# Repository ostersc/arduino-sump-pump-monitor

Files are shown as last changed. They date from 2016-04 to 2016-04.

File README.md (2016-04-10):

# arduino-sump-pump-monitor
Arduino project for ESP8266 to monitor backup sump pump and water level, sending alerts upon issues.

The project monitors my sump pump for when its backup pump engages, or when the main pump is running on battery power (due to power outage).  The project continually monitors the pumps, reporting data to thingspeak.com indicating the pump status.  The board is equiped with a LiPo battery backup, so it is still able to report in the event of a power outage.
Graph

## PUMP
I have the Basement Watchdog BW4000 Sump Pump, which has a backup pump, battery, and remote terminal to indicate alarms.
http://www.basementwatchdog.com/Basement_Watchdog_Combination_Systems.php
http://www.basementwatchdog.com/Accessories/Remote_Terminal.php
Any similar system could be used, or a homebrew sensor could be created, as all this "remote terminal" does is provide an open/closed circuit transition when triggering an alarm.

## HARDWARE
I'm using the Sparkfun ESP8266 Thing (https://www.sparkfun.com/products/13231).
The Adafruit Feather HUZZAH actually looks easier to program; it should work as well (https://www.adafruit.com/products/2821)
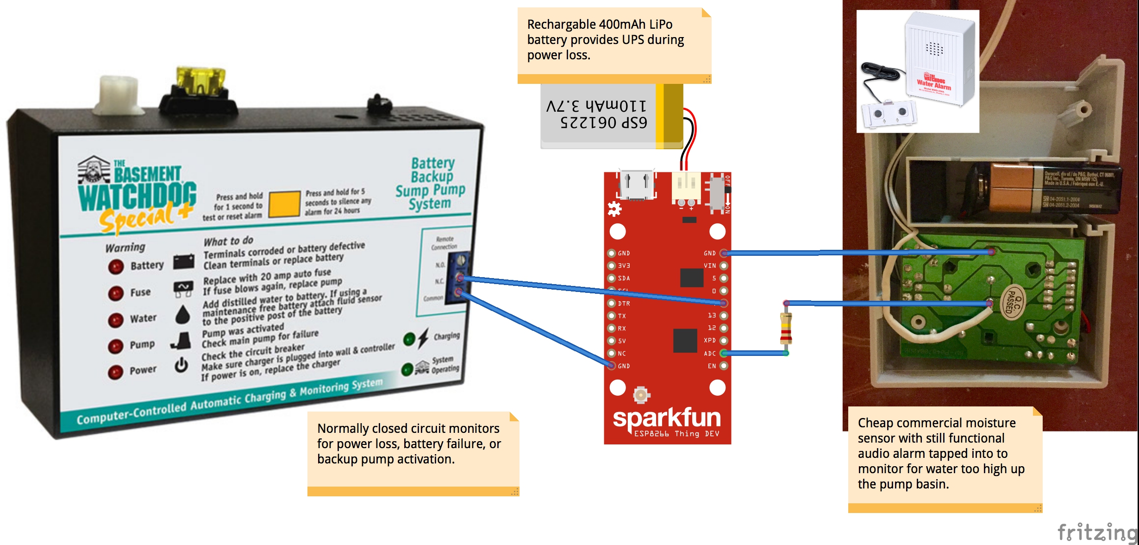
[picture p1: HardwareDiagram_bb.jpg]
Wiring


## CURRENT STATUS
*  Sump alarm monitoring (backup pump used, power loss, fuse, or battery issue)
*  Sump basin Water level alarm (moisture sensor mounted above backup float)
*  Reporting to thingspeak (signal strength, alarm state, alarm duration, alarm count)
* Email when alarm or water level alarm state entered (via https://temboo.com/arduino/others/send-an-email)

## TODO
* Battery level monitoring (and maybe deep sleep) (via https://learn.adafruit.com/using-ifttt-with-adafruit-io/wiring#battery-tracking)
* Collect settings and alert email via the wifi capture screen (via https://github.com/tzapu/WiFiManager#custom-parameters)
* 3D print an enclosure

## LIBRARIES
* https://github.com/tzapu/WiFiManager
* https://github.com/mathworks/thingspeak-arduino

## SETUP
- Create a file called Secrets.h, copying the commented out block from the ino sketch
- Create a thingspeak channel [here](https://thingspeak.com/)
  - The fields should be ```id alarm alarmduration alarmcount waterlevel wateralarmcount wateralarmduration rssi```
  - Edit the myChannelNumber and myWriteAPIKey in Secrets.h
  - Channel Setup
- Follow instructions on setting up Temboo account and gmail [here](https://temboo.com/arduino/others/send-an-email)
  - copy all the TEMBOO settings from the header section (normally Temboo.h) and put in Secrets.h
- You can setup additional alarms as needed (such as no data alarms, low wifi strength, etc) by using thingspeaks ability to trigger IFTTT events [as described here](http://www.makeuseof.com/tag/ifttt-connect-anything-maker-channel/).

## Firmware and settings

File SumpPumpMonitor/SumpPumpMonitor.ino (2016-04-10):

#include <ESP8266WiFi.h>
#include "WiFiManager.h"  //https://github.com/tzapu/WiFiManager
#include "Temboo.h"  //https://temboo.com/library/ https://github.com/arduino-libraries/Temboo
#include "ThingSpeak.h" //https://github.com/mathworks/thingspeak-arduino
#include "Secrets.h"
/**
   COPY THESE INTO A FILE CALLED Secrets.h AND REPLACE THE VALUES FOR YOUR ACCOUNT
  #define TEMBOO_ACCOUNT "your account"  // Your Temboo account name
  #define TEMBOO_APP_KEY_NAME "myFirstApp"  // Your Temboo app key name
  #define TEMBOO_APP_KEY "your key"  // Your Temboo app key

  #define EMAIL_USER "example@gmail.com"
  #define EMAIL_PASSWORD "asdfasdfasdfasdfasdf"
  #define EMAIL_TO "example@gmail.com"
  #define EMAIL_CC "example@gmail.com"
  #define EMAIL_FROM "example@gmail.com"

  unsigned long myChannelNumber = 123456;
  const char * myWriteAPIKey = "yourapikey";
*/

#define ALARM_EMAIL_SUBJECT "Sump Pump Alarm Triggered!"
#define WATER_EMAIL_SUBJECT "Water in Sump Pump!"

const char* SSID = "SumpPumpMonitor";

//Thing's onboard LED
const int LED_PIN = 5;
// other pings available on Thing
const int ANALOG_PIN = A0;
//const int DIGITAL_PIN_1 = 0;
//const int DIGITAL_PIN_2 = 4;
//const int DIGITAL_PIN_3 = 12;
//const int DIGITAL_PIN_4 = 13;
const int ALARM_PIN = 4;

const int NUM_READINGS = 20;

int moistureReadings[NUM_READINGS];   // the readings from the analog input
int moistureReadIndex = 0;            // the index of the current reading
int moistureTotal = 0;                // the running total
int moistureAverage = 0;              // the average
int moistureState = LOW;
int moistureAlarmCount = 0;
const int moistureThreshold = 250;
unsigned long lastMoistureAlarm = 0;
#define DEBUG_MOISTURE false

//thingspeak only lets report every 15 seconds or so
const unsigned long postRate = 15000;
unsigned long lastPost = 0;
unsigned long lastAlarm = 0;
int alarmState = LOW;
int alarmCount = 0;
String macAddress;

// Use WiFiClient class to create TCP connections
WiFiClient client;

//comment out to disable debug output
//#define DEBUG
//WARNING: printing to the serial port while sending data over wifi, corrupts the data (at least with sparkfun's board posting to phant)

#ifdef DEBUG
#define DEBUG_PRINT(x)  Serial.print (x)
#define DEBUG_PRINTLN(x)  Serial.println (x)
#else
#define DEBUG_PRINT(x)
#define DEBUG_PRINTLN(x)
#endif


void configModeCallback (WiFiManager *myWiFiManager) {
  DEBUG_PRINTLN("Entered config mode");
  DEBUG_PRINTLN(WiFi.softAPIP());
  //if you used auto generated SSID, print it
  DEBUG_PRINTLN(myWiFiManager->getConfigPortalSSID());
}

void setup() {
  Serial.begin(9600);
  delay(100);
  DEBUG_PRINTLN();

  //  pinMode(DIGITAL_PIN_1, INPUT_PULLUP);
  //  pinMode(DIGITAL_PIN_2, INPUT_PULLUP);
  //  pinMode(DIGITAL_PIN_3, INPUT_PULLUP);
  //  pinMode(DIGITAL_PIN_4, INPUT_PULLUP);
  pinMode(ALARM_PIN, INPUT_PULLUP);
  pinMode(ANALOG_PIN, INPUT);
  pinMode(LED_PIN, OUTPUT);
  digitalWrite(LED_PIN, LOW);

  WiFiManager wifiManager;

  //reset settings - for testing captive wifi
  //wifiManager.resetSettings();

  //set callback that gets called when connecting to previous WiFi fails, and enters Access Point mode
  wifiManager.setAPCallback(configModeCallback);

  //fetches ssid and pass and tries to connect
  //if it does not connect it starts an access point with the specified name
  //here  "AutoConnectAP"
  //and goes into a blocking loop awaiting configuration
  if (!wifiManager.autoConnect(SSID)) {
    DEBUG_PRINTLN("failed to connect and hit timeout");
    DEBUG_PRINT(".");
    //reset and try again, or maybe put it to deep sleep
    ESP.reset();
    delay(1000);
  }

  macAddress = WiFi.macAddress();

  DEBUG_PRINTLN("");
  DEBUG_PRINTLN("WiFi connected");
  DEBUG_PRINTLN("IP address: ");
  DEBUG_PRINTLN(WiFi.localIP());
  DEBUG_PRINTLN("MAC: ");
  DEBUG_PRINTLN(macAddress);

  ThingSpeak.begin(client);
}

void sendSumpAlert(String alert) {
  DEBUG_PRINTLN("Sending alert email!");
  TembooChoreo SendEmailChoreo(client);

  // Invoke the Temboo client
  SendEmailChoreo.begin();

  // Set Temboo account credentials
  SendEmailChoreo.setAccountName(TEMBOO_ACCOUNT);
  SendEmailChoreo.setAppKeyName(TEMBOO_APP_KEY_NAME);
  SendEmailChoreo.setAppKey(TEMBOO_APP_KEY);

  // Set Choreo inputs
  SendEmailChoreo.addInput("CC", EMAIL_CC);
  SendEmailChoreo.addInput("FromAddress", EMAIL_FROM);
  SendEmailChoreo.addInput("Username", EMAIL_USER);
  SendEmailChoreo.addInput("ToAddress", EMAIL_TO);
  SendEmailChoreo.addInput("Subject", alert);
  SendEmailChoreo.addInput("Password", EMAIL_PASSWORD);
  //TODO: add current values here
  SendEmailChoreo.addInput("MessageBody", alert);

  // Identify the Choreo to run
  SendEmailChoreo.setChoreo("/Library/Google/Gmail/SendEmail");

  // Run the Choreo; when results are available, print them to serial
  SendEmailChoreo.run();

  while (SendEmailChoreo.available()) {
    char c = SendEmailChoreo.read();
    DEBUG_PRINT(c);
  }
  SendEmailChoreo.close();
  delay(250);
  if (client.connected()) {
    client.stop(); // stop() closes a TCP connection.
    DEBUG_PRINTLN("Connection closed.");
  } else {
    DEBUG_PRINTLN("Connection was not active.");
  }
}

void updateMoistureLevel() {
  int moistureLevel = analogRead(ANALOG_PIN);

  // subtract the last reading:
  moistureTotal = moistureTotal - moistureReadings[moistureReadIndex];
  // read from the sensor:
  moistureReadings[moistureReadIndex] = moistureLevel;
  // add the reading to the total:
  moistureTotal = moistureTotal + moistureReadings[moistureReadIndex];
  // advance to the next position in the array:
  moistureReadIndex += 1;

  // if we're at the end of the array...
  if (moistureReadIndex >= NUM_READINGS) {
    // ...wrap around to the beginning:
    moistureReadIndex = 0;
  }

  // calculate the average:
  moistureAverage = moistureTotal / NUM_READINGS;

  if (moistureState == LOW) {
    if (moistureAverage > moistureThreshold) {
      lastMoistureAlarm = millis();
      moistureAlarmCount++;
      moistureState = HIGH;
      DEBUG_PRINT("Water detected at ");
      DEBUG_PRINTLN(lastMoistureAlarm);
      DEBUG_PRINT("Moisture detected! The moisture level is: ");
      DEBUG_PRINTLN(moistureAverage);
      sendSumpAlert(WATER_EMAIL_SUBJECT);
    }
  } else {
    if (moistureAverage <= moistureThreshold ) {
      DEBUG_PRINT("Water alarm ended at ");
      DEBUG_PRINTLN(millis());
      DEBUG_PRINT("Lasting for ");
      DEBUG_PRINT((millis() - lastMoistureAlarm) / 1000);
      DEBUG_PRINTLN(" seconds.");
      DEBUG_PRINT("Moisture level below alarm threshold: ");
      DEBUG_PRINTLN(moistureAverage);
      moistureState = LOW;
    }
  }

  if (DEBUG_MOISTURE) {
    DEBUG_PRINT("\tCurrent moisture level:");
    DEBUG_PRINTLN(moistureLevel);
    DEBUG_PRINT("Moisture avg:  ");
    DEBUG_PRINTLN(moistureAverage);
  }
}


int checkAndReport() {
  DEBUG_PRINT("Sending data.");

  int oldAlarmState = alarmState;
  alarmState = digitalRead(ALARM_PIN);

  if (oldAlarmState != alarmState) {
    if (alarmState == HIGH) {
      lastAlarm = millis();
      alarmCount++;
      DEBUG_PRINT("Alarm detected at ");
      DEBUG_PRINTLN(lastAlarm);
      sendSumpAlert(ALARM_EMAIL_SUBJECT);
    } else if (alarmState == LOW) {
      DEBUG_PRINT("Alarm ended at ");
      DEBUG_PRINTLN(millis());
      DEBUG_PRINT("Lasting for ");
      DEBUG_PRINT((millis() - lastAlarm) / 1000);
      DEBUG_PRINTLN(" seconds.");
    }
  }

  int alarmDuration = 0;
  if (alarmState == HIGH) {
    alarmDuration = (millis() - lastAlarm) / 1000;
  }

  int moistureAlarmDuration = 0;
  if (moistureState == HIGH) {
    moistureAlarmDuration = (millis() - lastMoistureAlarm) / 1000;
  }

  // LED turns on when we enter, it'll go off when we
  // successfully post.
  digitalWrite(LED_PIN, HIGH);

  ThingSpeak.setField(1, macAddress);
  ThingSpeak.setField(2, alarmState);
  ThingSpeak.setField(3, alarmDuration);
  ThingSpeak.setField(4, alarmCount);
  ThingSpeak.setField(5, moistureAverage);
  ThingSpeak.setField(6, moistureAlarmCount);
  ThingSpeak.setField(7,  moistureAlarmDuration);
  ThingSpeak.setField(8,  WiFi.RSSI());
  DEBUG_PRINT("Sending data thingspeak.");
  // Write the fields that you've set all at once.
  ThingSpeak.writeFields(myChannelNumber, myWriteAPIKey);

  // Before we exit, turn the LED off.
  digitalWrite(LED_PIN, LOW);
  return 1;
}

void loop() {
  delay(100);
  if (millis() - lastPost >= postRate) {
    updateMoistureLevel();
    if (checkAndReport()) {
      lastPost = millis();
    } else {
      delay(2000);
    }
  }
}

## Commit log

2016-04-03 switched to thingspeak from phant
2016-04-04 fixed delay for rollover
    [SumpPumpMonitor.ino]
2016-04-10 Added moisture sensor reporting and alarm
2016-04-10 added diagrams
    [HardwareDiagram.fzz]
